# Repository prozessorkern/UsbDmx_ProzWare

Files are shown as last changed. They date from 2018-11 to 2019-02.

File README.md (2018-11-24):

# UsbDmx_ProzWare

Here you find the refactored hardware development (schematics and layout) of USB DMX from http://www.digital-enlightenment.de/usbdmx.htm.

Credit goes to Michael Dreschmann from http://www.digital-enlightenment.de.

This repo adds KiCad schematics and layout in SMD technology with a complete board design with onboard XLR connectors.

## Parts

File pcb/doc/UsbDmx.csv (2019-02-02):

Id | Designator | Package | Quantity | Designation | Supplier and ref
1 | U201,U206 | SO-8_3.9x4.9mm_P1.27mm | 2 | SN75176
2 | CON202 | NC3MAH_XLR_M | 1 | XLR3_M_GROUND
3 | CON101 | TC2050-IDC | 1 | 10PIN_ISP_AVR
4 | D101 | LED_SMD_0603 | 1 | LED
5 | CON201 | NC3FAH2_XLR_F | 1 | XLR3_F_GROUND
6 | D201 | LED_SMD_0603 | 1 | LED_TX
7 | D204 | LED_SMD_0603 | 1 | LED_DMX
8 | D205 | LED_SMD_0603 | 1 | LED_RX
9 | J102 | BARREL_JACK_CLIFF | 1 | Barrel_Jack
10 | U202,U204 | GULLWING_8 | 2 | 6N137
11 | U205 | SIP7 | 1 | AM2D-0505SZ
12 | L101,L201,L202,L204 | 1271.1001 | 4 | 1271.1001
13 | G*** | Shimatta_SolderMask | 1 | LOGO
14 | L203 | inductor_1812 | 1 | 18u
15 | U104 | SOIC-28W_8.7x18.7mm_Pitch1.27mm | 1 | AS6C6264
16 | U106 | TQFP-44_10x10mm_P0.8mm | 1 | ATMEGA8515-16AU
17 | C101,C106,C107,C108,C112,C114,C115,C117,C118,C119,C201,C202,C204,C205,C206,C210,C213,C215,C216 | C_0603_1608Metric_Pad1.05x0.95mm_HandSolder | 19 | 100n
18 | C102,C103 | C_0603_1608Metric_Pad1.05x0.95mm_HandSolder | 2 | 15p
19 | C104,C105,C111 | C_0805_2012Metric_Pad1.15x1.40mm_HandSolder | 3 | 100n
20 | C109 | CP_Radial_D4.0mm_P1.50mm | 1 | 1u
21 | C110 | CP_Radial_D10.0mm_P5.00mm | 1 | 470u
22 | C113 | CP_Radial_D6.3mm_P2.50mm | 1 | 100u
23 | C116 | CP_Radial_D5.0mm_P2.00mm | 1 | 10u
24 | C203,C212,C214 | C_Disc_D7.5mm_W5.0mm_P7.50mm | 3 | 470p 2kV
25 | C207,C211 | CP_Radial_D5.0mm_P2.00mm | 2 | 47u
26 | C208,C209 | C_0805_2012Metric_Pad1.15x1.40mm_HandSolder | 2 | 2u2
27 | D102,D103,D104,D105 | D_SMA_Handsoldering | 4 | SS15
28 | D202,D203,D206,D207 | D_MiniMELF | 4 | 1N4148
29 | F101 | Fuse_1206_3216Metric_Pad1.42x1.75mm_HandSolder | 1 | 0.375A
30 | J101 | USB_B_OST_USB-B1HSxx_Horizontal | 1 | USB_B
31 | JP101 | PinHeader_1x02_P2.54mm_Vertical | 1 | programming mode
32 | Q201,Q203 | SOT-23 | 2 | BC817
33 | Q202 | SOT-23 | 1 | BC807
34 | R101 | R_0603_1608Metric_Pad1.05x0.95mm_HandSolder | 1 | 100
35 | R102 | R_0603_1608Metric_Pad1.05x0.95mm_HandSolder | 1 | 1M
36 | R103,R104 | R_0603_1608Metric_Pad1.05x0.95mm_HandSolder | 2 | 22
37 | R105 | R_0603_1608Metric_Pad1.05x0.95mm_HandSolder | 1 | 1k5
38 | R106,R210,R219 | R_0603_1608Metric_Pad1.05x0.95mm_HandSolder | 3 | 1k
39 | R107,R108,R204,R208 | R_0603_1608Metric_Pad1.05x0.95mm_HandSolder | 4 | 10k
40 | R109,R110 | R_0603_1608Metric_Pad1.05x0.95mm_HandSolder | 2 | 2k2
41 | R111,R112,R211,R220 | R_0603_1608Metric_Pad1.05x0.95mm_HandSolder | 4 | 47k
42 | R201,R214 | R_MiniMELF_MMA-0204 | 2 | 120
43 | R202,R209,R212 | R_0603_1608Metric_Pad1.05x0.95mm_HandSolder | 3 | 470
44 | R203,R205 | R_MiniMELF_MMA-0204 | 2 | 1
45 | R206,R215,R216,R217 | R_MiniMELF_MMA-0204 | 4 | 10
46 | R207,R213,R218 | R_0603_1608Metric_Pad1.05x0.95mm_HandSolder | 3 | 220
47 | U101 | SOIC-20W_7.5x12.8mm_P1.27mm | 1 | 74LS573
48 | U102 | SOT-23-6 | 1 | USBLC6-2SC6
49 | U103 | SOIC-28W_7.5x17.9mm_P1.27mm | 1 | USBN9604-28M
50 | U105 | TO-263-2 | 1 | L7805
51 | U203,U207 | SOT-23_Handsoldering | 2 | PESD5V0S2BT
52 | Y101 | Crystal_HC49-U_Vertical | 1 | 24MHz
53 | REF** | KiCad-Logo2_8mm_SilkScreen | 1 | KiCad-Logo2_8mm_SilkScreen
54 | REF** | WEEE-Logo_8.4x12mm_SilkScreen | 1 | WEEE-Logo_8.4x12mm_SilkScreen
55 | REF** | ESD-Logo_8.9x8mm_SilkScreen | 1 | ESD-Logo_8.9x8mm_SilkScreen

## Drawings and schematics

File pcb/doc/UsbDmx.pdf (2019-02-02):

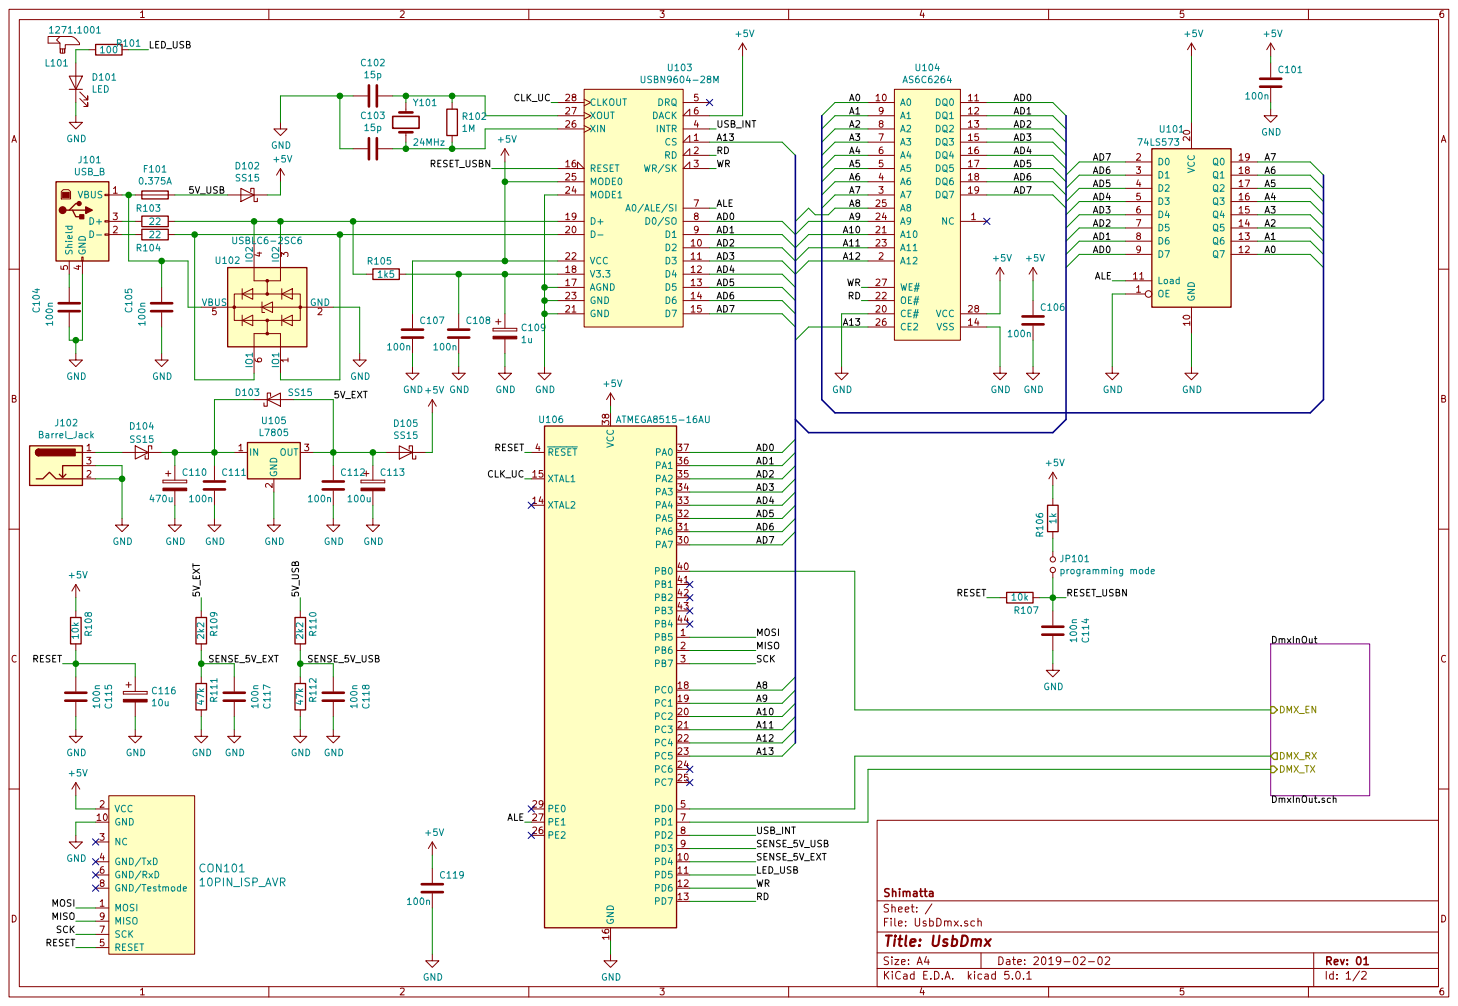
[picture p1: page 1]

RESET SCK MISO MOSI GND

File: UsbDmx.sch Sheet: / Shimatta

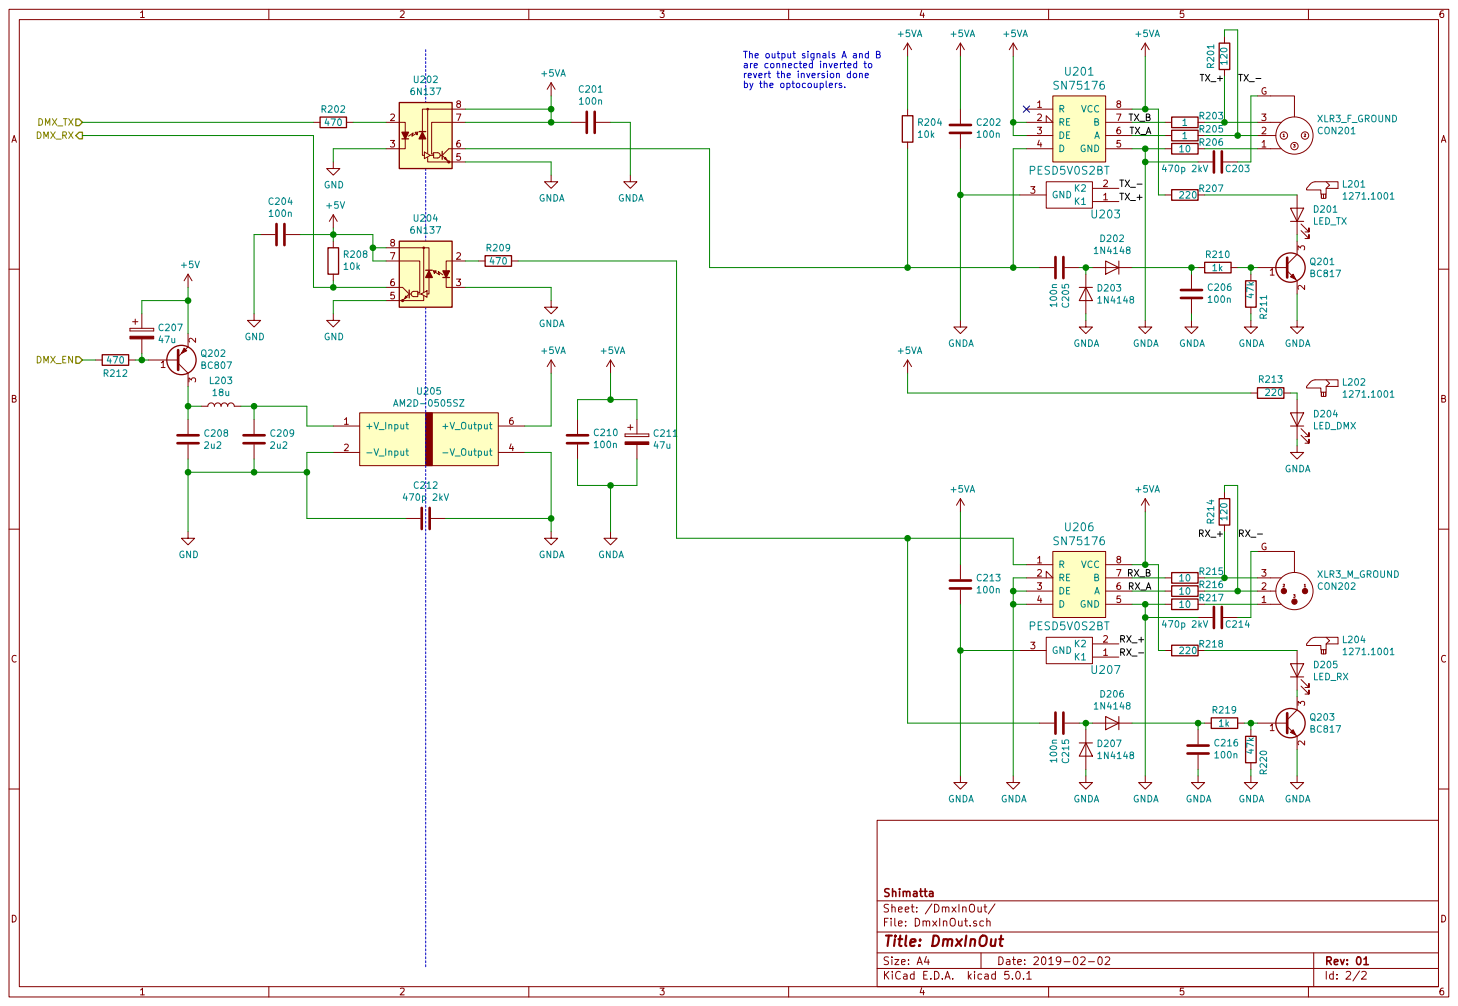
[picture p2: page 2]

The output signals A and B
are connected inverted to
revert the inversion done

Id: 2/2 Title: DmxInOut File: DmxInOut.sch Sheet: /DmxInOut/ Shimatta

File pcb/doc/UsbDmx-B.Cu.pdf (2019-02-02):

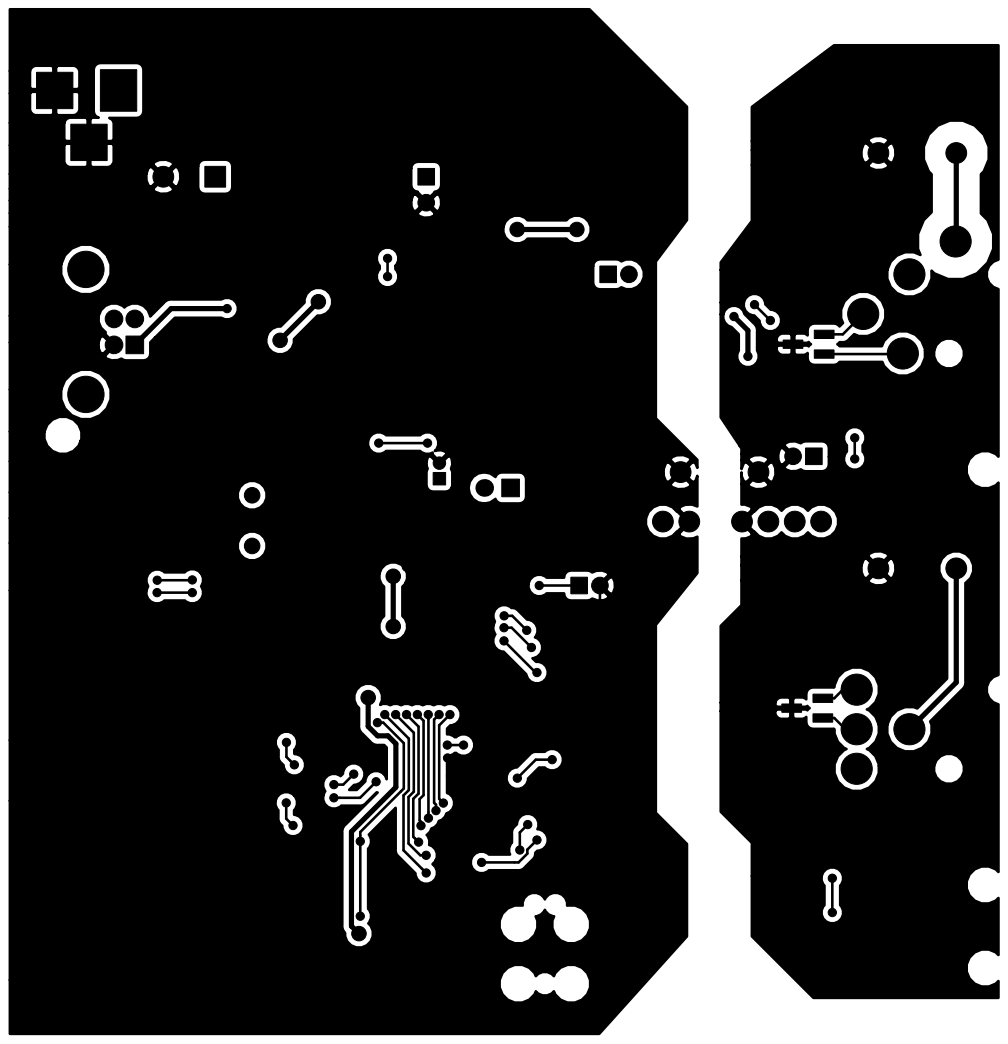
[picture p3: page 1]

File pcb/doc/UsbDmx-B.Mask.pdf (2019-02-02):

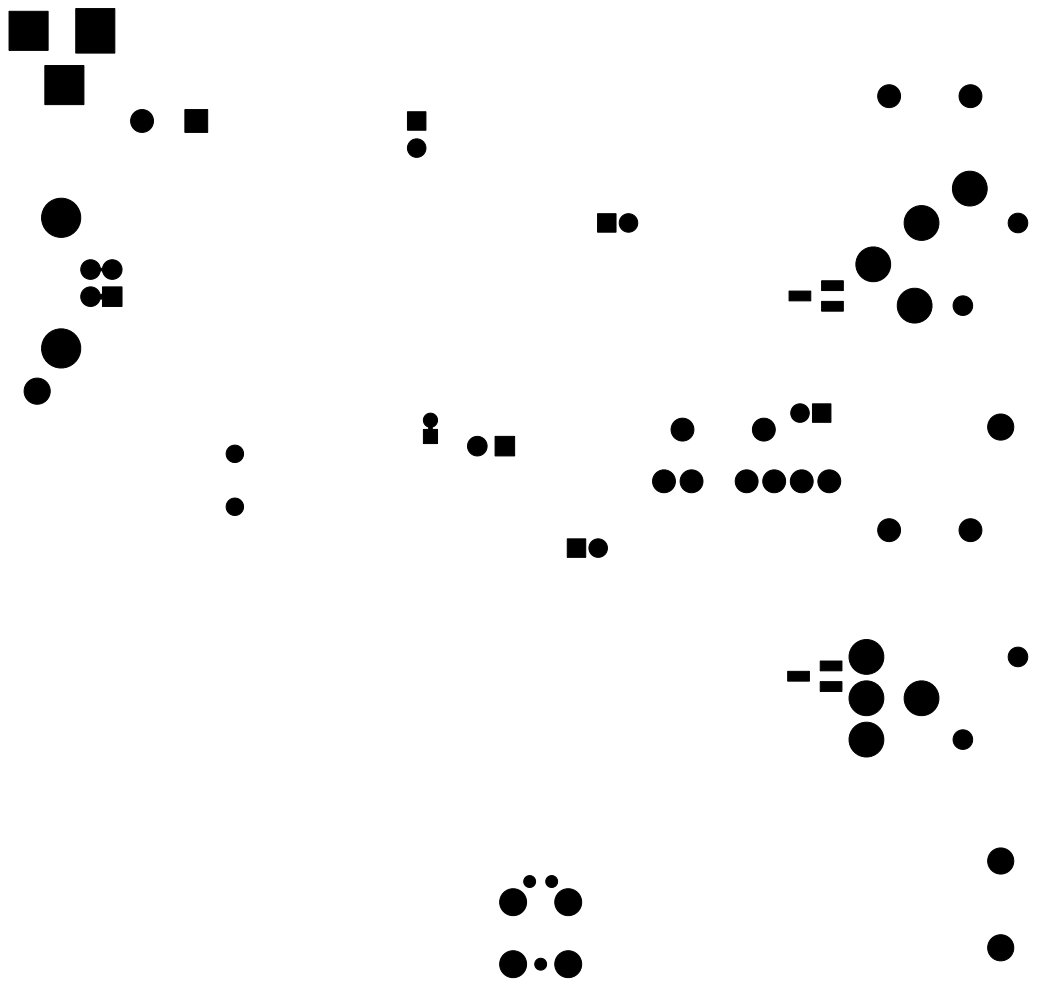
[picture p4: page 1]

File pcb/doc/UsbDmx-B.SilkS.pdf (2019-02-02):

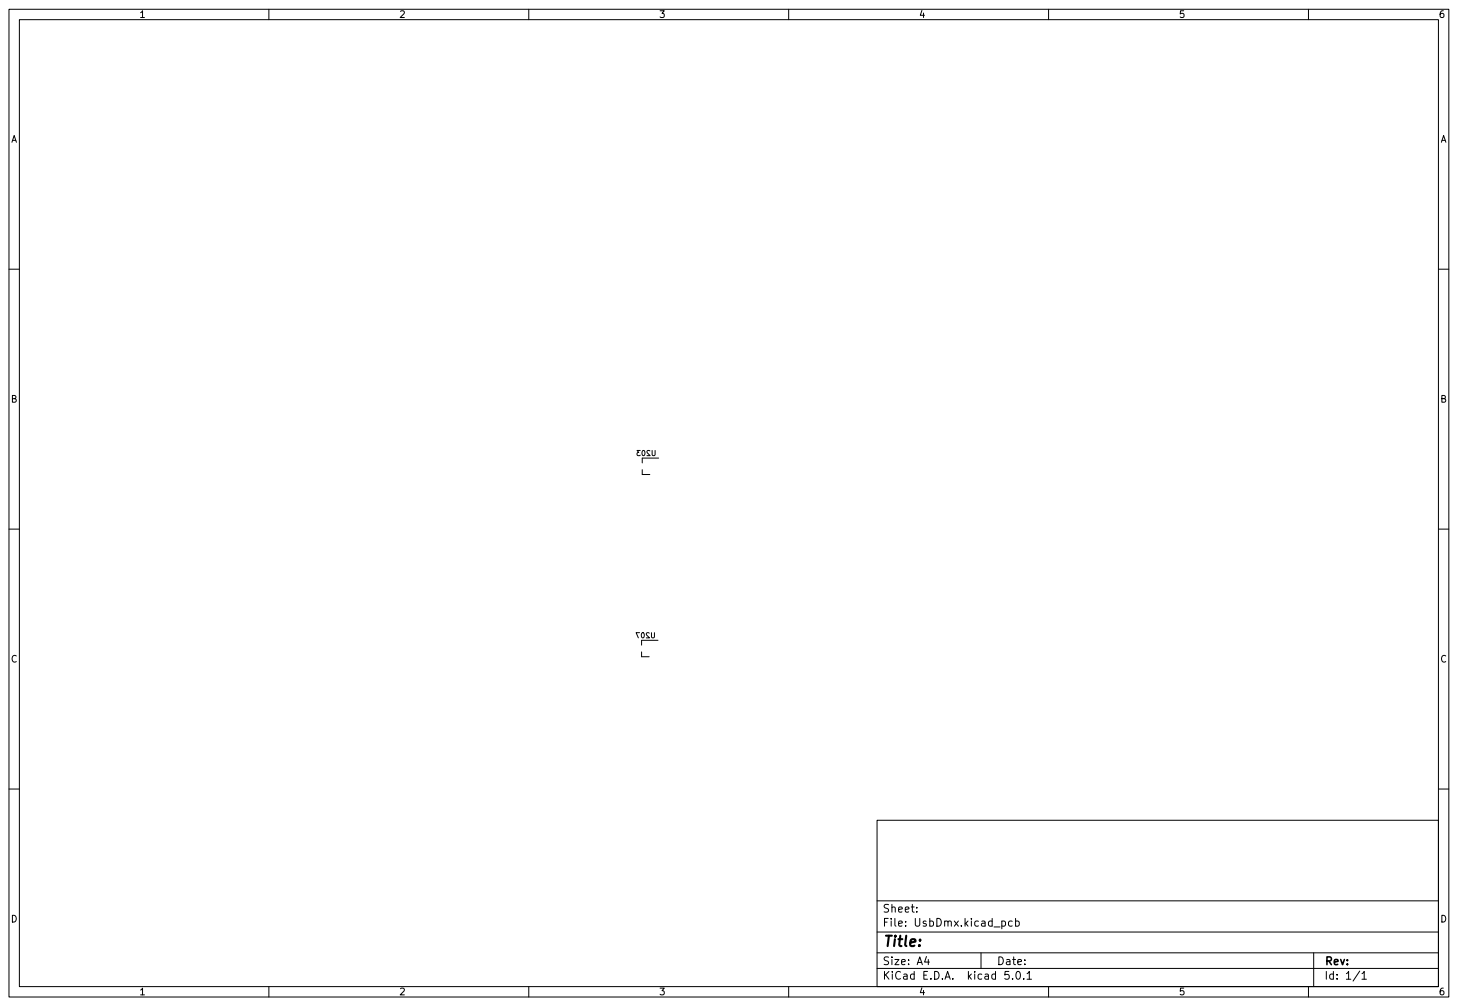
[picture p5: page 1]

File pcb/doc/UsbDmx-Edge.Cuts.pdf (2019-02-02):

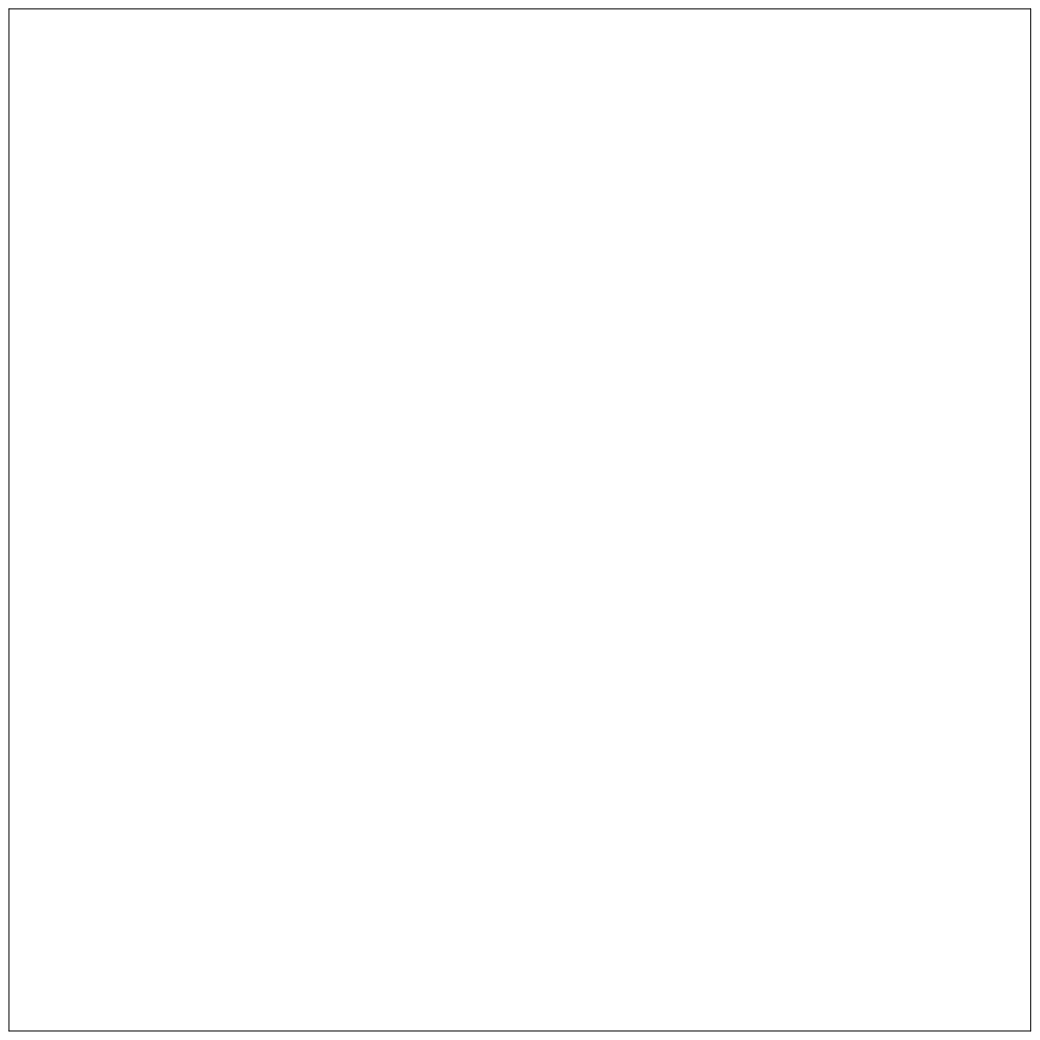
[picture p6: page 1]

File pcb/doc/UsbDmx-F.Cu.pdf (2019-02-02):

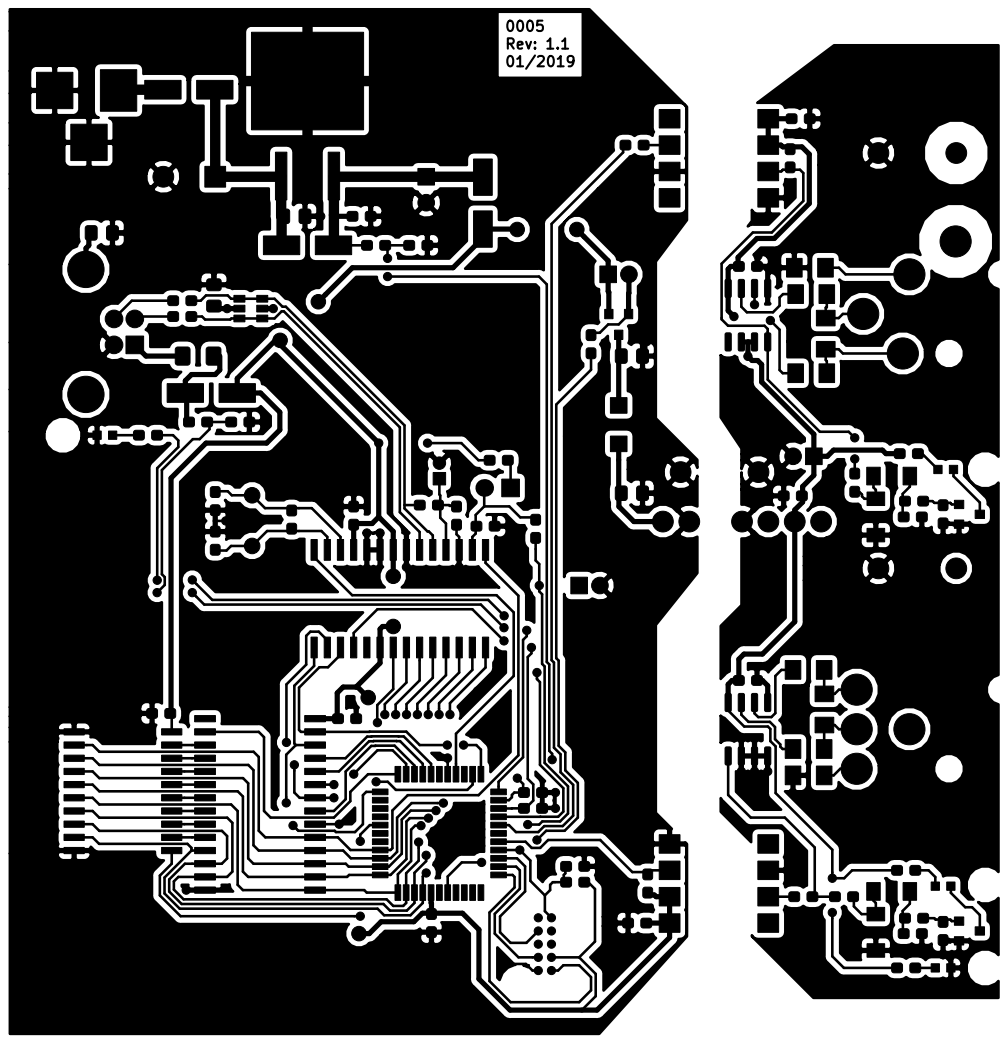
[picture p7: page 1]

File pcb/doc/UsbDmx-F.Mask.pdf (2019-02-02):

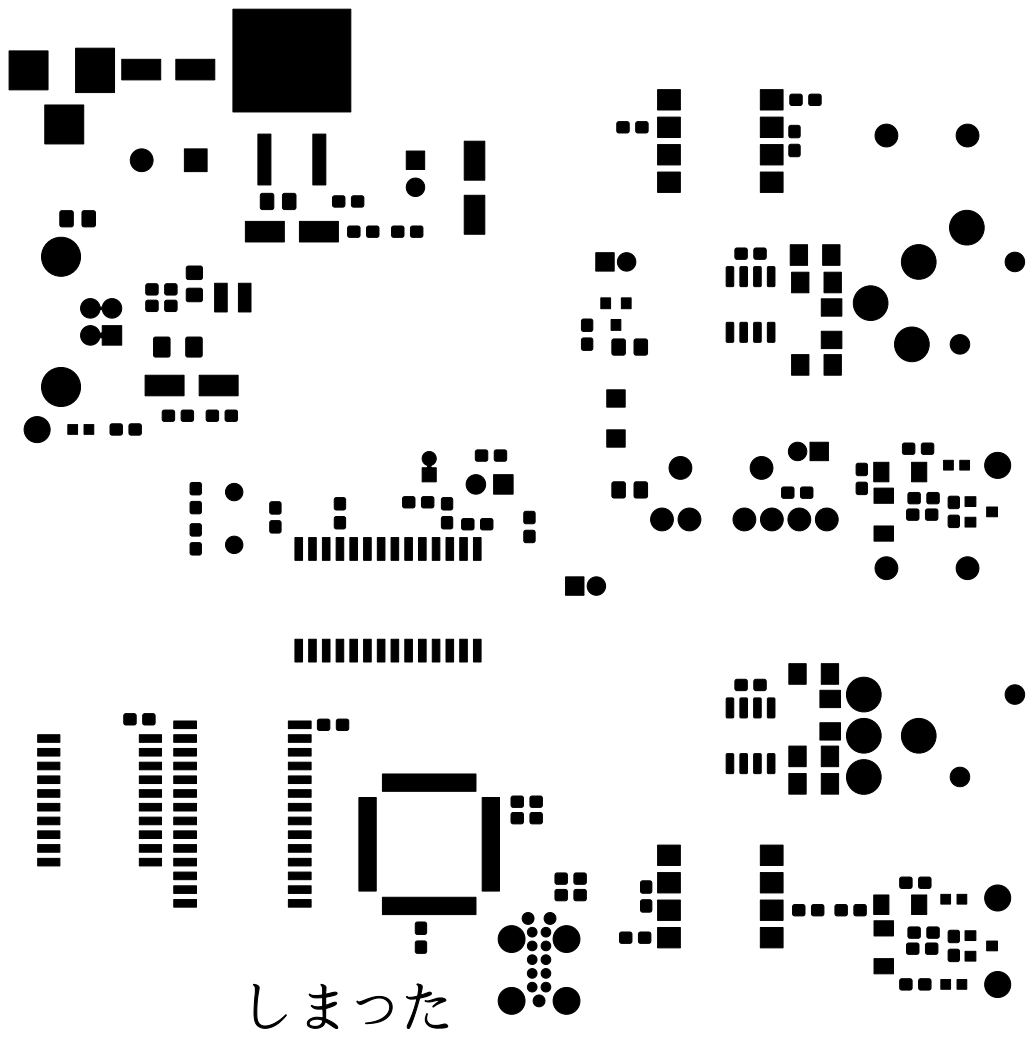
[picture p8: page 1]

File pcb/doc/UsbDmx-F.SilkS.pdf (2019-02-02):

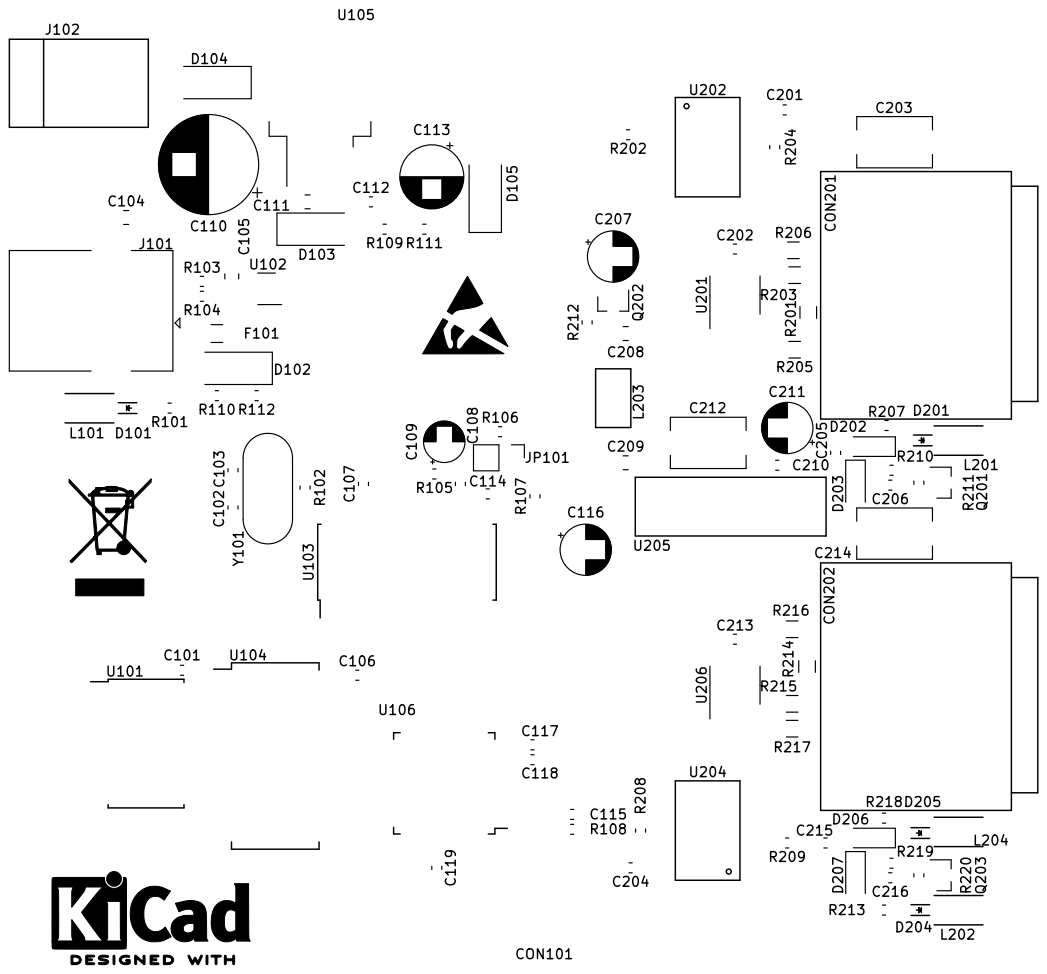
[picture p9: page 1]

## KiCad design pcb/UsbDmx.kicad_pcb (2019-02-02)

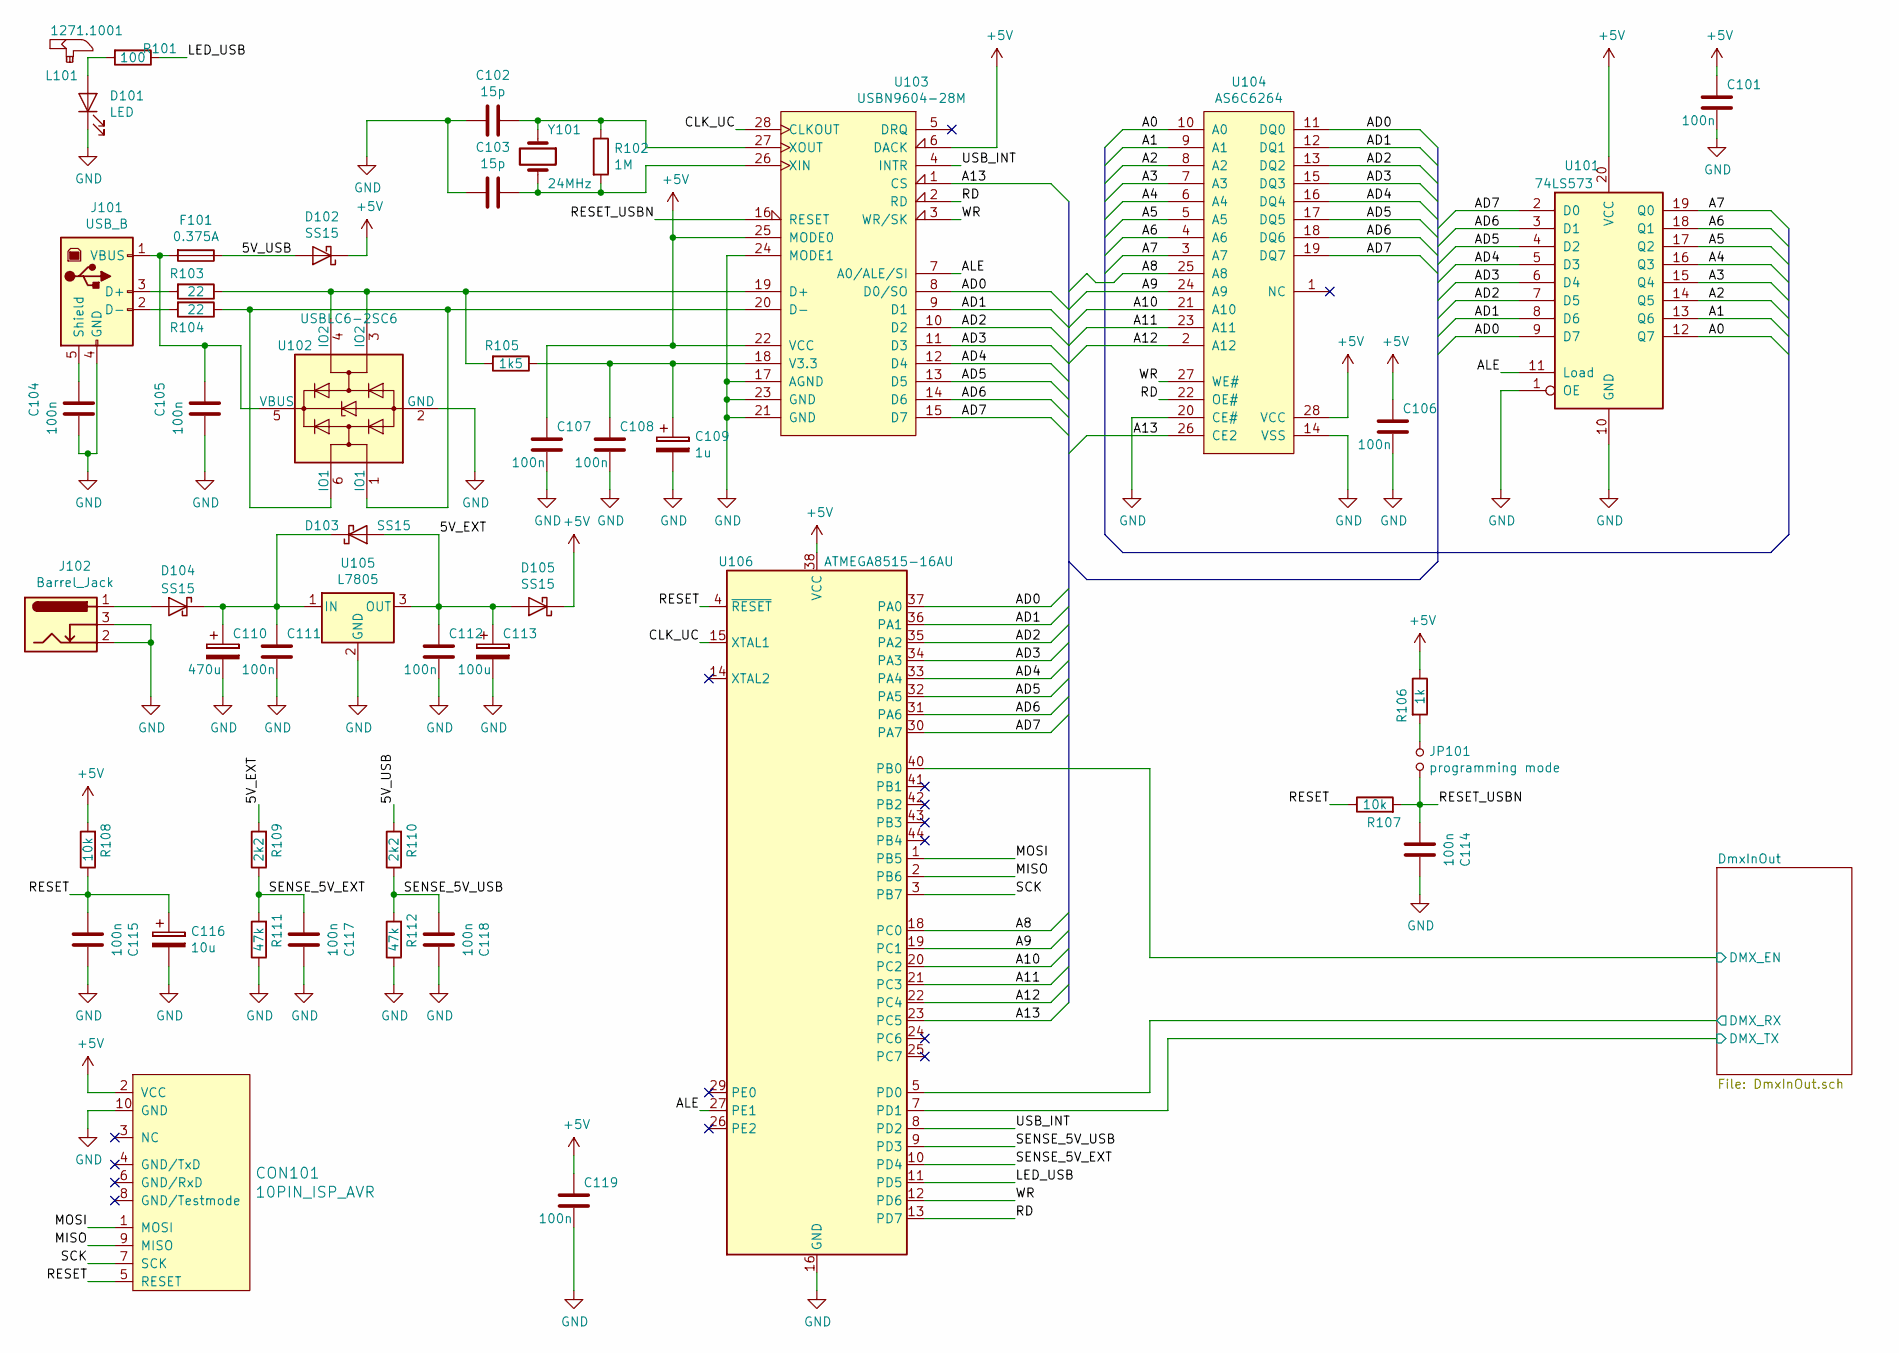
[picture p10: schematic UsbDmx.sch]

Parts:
C101, C106, C107, C108, C112, C114, C115, C117, C118, C119: 100n; C_0603_1608Metric_Pad1.05x0.95mm_HandSolder
C102, C103: 15p; C_0603_1608Metric_Pad1.05x0.95mm_HandSolder
C104, C105, C111: 100n; C_0805_2012Metric_Pad1.15x1.40mm_HandSolder
C109: 1u; CP_Radial_D4.0mm_P1.50mm
C110: 470u; CP_Radial_D10.0mm_P5.00mm
C113: 100u; CP_Radial_D6.3mm_P2.50mm
C116: 10u; CP_Radial_D5.0mm_P2.00mm
CON101: 10PIN_ISP_AVR; TC2050-IDC
D101: LED; LED_SMD_0603
D102, D103, D104, D105: SS15; D_SMA_Handsoldering
F101: 0.375A; Fuse_1206_3216Metric_Pad1.42x1.75mm_HandSolder
J101: USB_B; USB_B_OST_USB-B1HSxx_Horizontal
J102: Barrel_Jack; BARREL_JACK_CLIFF
JP101: programming mode; PinHeader_1x02_P2.54mm_Vertical
L101: 1271.1001
R101: 100; R_0603_1608Metric_Pad1.05x0.95mm_HandSolder
R102: 1M; R_0603_1608Metric_Pad1.05x0.95mm_HandSolder
R103, R104: 22; R_0603_1608Metric_Pad1.05x0.95mm_HandSolder
R105: 1k5; R_0603_1608Metric_Pad1.05x0.95mm_HandSolder
R106: 1k; R_0603_1608Metric_Pad1.05x0.95mm_HandSolder
R107, R108: 10k; R_0603_1608Metric_Pad1.05x0.95mm_HandSolder
R109, R110: 2k2; R_0603_1608Metric_Pad1.05x0.95mm_HandSolder
R111, R112: 47k; R_0603_1608Metric_Pad1.05x0.95mm_HandSolder
U101: 74LS573; SOIC-20W_7.5x12.8mm_P1.27mm
U102: USBLC6-2SC6; SOT-23-6
U103: USBN9604-28M; SOIC-28W_7.5x17.9mm_P1.27mm
U104: AS6C6264; SOIC-28W_8.7x18.7mm_Pitch1.27mm
U105: L7805; TO-263-2
U106: ATMEGA8515-16AU; TQFP-44_10x10mm_P0.8mm
Y101: 24MHz; Crystal_HC49-U_Vertical

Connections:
+5V: C101.1, C106.1, C107.1, C119.1, CON101.2 (VCC), D102.1 (K), D105.1 (K), R106.1, R108.2, U101.20 (VCC), U103.6 (DACK), U103.22 (VCC), U103.25 (MODE0), U104.28 (VCC), U106.38 (VCC); also elsewhere on the board
/5V_EXT: C112.1, C113.1, D103.2 (A), D105.2 (A), R109.2, U105.3 (OUT)
/5V_USB: D102.2 (A), F101.1, R110.2
/A0: U101.12 (Q7), U104.10 (A0)
/A1: U101.13 (Q6), U104.9 (A1)
/A2: U101.14 (Q5), U104.8 (A2)
/A3: U101.15 (Q4), U104.7 (A3)
/A4: U101.16 (Q3), U104.6 (A4)
/A5: U101.17 (Q2), U104.5 (A5)
/A6: U101.18 (Q1), U104.4 (A6)
/A7: U101.19 (Q0), U104.3 (A7)
/A8: U104.25 (A8), U106.18 (PC0)
/A9: U104.24 (A9), U106.19 (PC1)
/A10: U104.21 (A10), U106.20 (PC2)
/A11: U104.23 (A11), U106.21 (PC3)
/A12: U104.2 (A12), U106.22 (PC4)
/A13: U103.1 (CS), U104.26 (CE2), U106.23 (PC5)
/AD0: U101.9 (D7), U103.8 (D0/SO), U104.11 (DQ0), U106.37 (PA0)
/AD1: U101.8 (D6), U103.9 (D1), U104.12 (DQ1), U106.36 (PA1)
/AD2: U101.7 (D5), U103.10 (D2), U104.13 (DQ2), U106.35 (PA2)
/AD3: U101.6 (D4), U103.11 (D3), U104.15 (DQ3), U106.34 (PA3)
/AD4: U101.5 (D3), U103.12 (D4), U104.16 (DQ4), U106.33 (PA4)
/AD5: U101.4 (D2), U103.13 (D5), U104.17 (DQ5), U106.32 (PA5)
/AD6: U101.3 (D1), U103.14 (D6), U104.18 (DQ6), U106.31 (PA6)
/AD7: U101.2 (D0), U103.15 (D7), U104.19 (DQ7), U106.30 (PA7)
/ALE: U101.11 (Load), U103.7 (A0/ALE/SI), U106.27 (PE1)
/CLK_UC: U103.28 (CLKOUT), U106.15 (XTAL1)
/DmxInOut/DMX_EN: U106.40 (PB0); also elsewhere on the board
/DmxInOut/DMX_RX: U106.5 (PD0); also elsewhere on the board
/DmxInOut/DMX_TX: U106.7 (PD1); also elsewhere on the board
/LED_USB: R101.1, U106.11 (PD5)
/MISO: CON101.9 (MISO), U106.2 (PB6)
/MOSI: CON101.1 (MOSI), U106.1 (PB5)
/RD: U103.2 (RD), U104.22 (OE#), U106.13 (PD7)
/RESET: C115.2, C116.1, CON101.5 (RESET), R107.1, R108.1, U106.4 (~RESET)
/RESET_USBN: C114.2, JP101.2, R107.2, U103.16 (RESET)
/SCK: CON101.7 (SCK), U106.3 (PB7)
/SENSE_5V_EXT: C117.2, R109.1, R111.2, U106.10 (PD4)
/SENSE_5V_USB: C118.2, R110.1, R112.2, U106.9 (PD3)
/USB_INT: U103.4 (INTR), U106.8 (PD2)
/WR: U103.3 (WR/SK), U104.27 (WE#), U106.12 (PD6)
GND: C101.2, C102.2, C103.2, C104.2, C105.2, C106.2, C107.2, C108.2, C109.2, C110.2, C111.2, C112.2, C113.2, C114.1, C115.1, C116.2, C117.1, C118.1, C119.2, CON101.10 (GND), D101.1 (K), J101.4 (GND), J102.2, J102.3, R111.1, R112.1, U101.1 (OE), U101.10 (GND), U102.2 (GND), U103.17 (AGND), U103.21 (GND), U103.23 (GND), U103.24 (MODE1), U104.14 (VSS), U104.20 (CE#), U105.2 (GND), U106.16 (GND); also elsewhere on the board
unnamed: C102.1, R102.1, U103.27 (XOUT), Y101.1
unnamed: C103.1, R102.2, U103.26 (XIN), Y101.2
unnamed: C104.1, J101.5 (Shield)
unnamed: C105.1, F101.2, J101.1 (VBUS), U102.5 (VBUS)
unnamed: C108.1, C109.1, R105.1, U103.18 (V3.3)
unnamed: C110.1, C111.1, D103.1 (K), D104.1 (K), U105.1 (IN)
unnamed: D101.2 (A), R101.2
unnamed: D104.2 (A), J102.1
unnamed: J101.2 (D-), R104.2
unnamed: J101.3 (D+), R103.2
unnamed: JP101.1, R106.2
unnamed: R103.1, R105.2, U102.3 (IO2), U102.4 (IO2), U103.19 (D+)
unnamed: R104.1, U102.1 (IO1), U102.6 (IO1), U103.20 (D-)

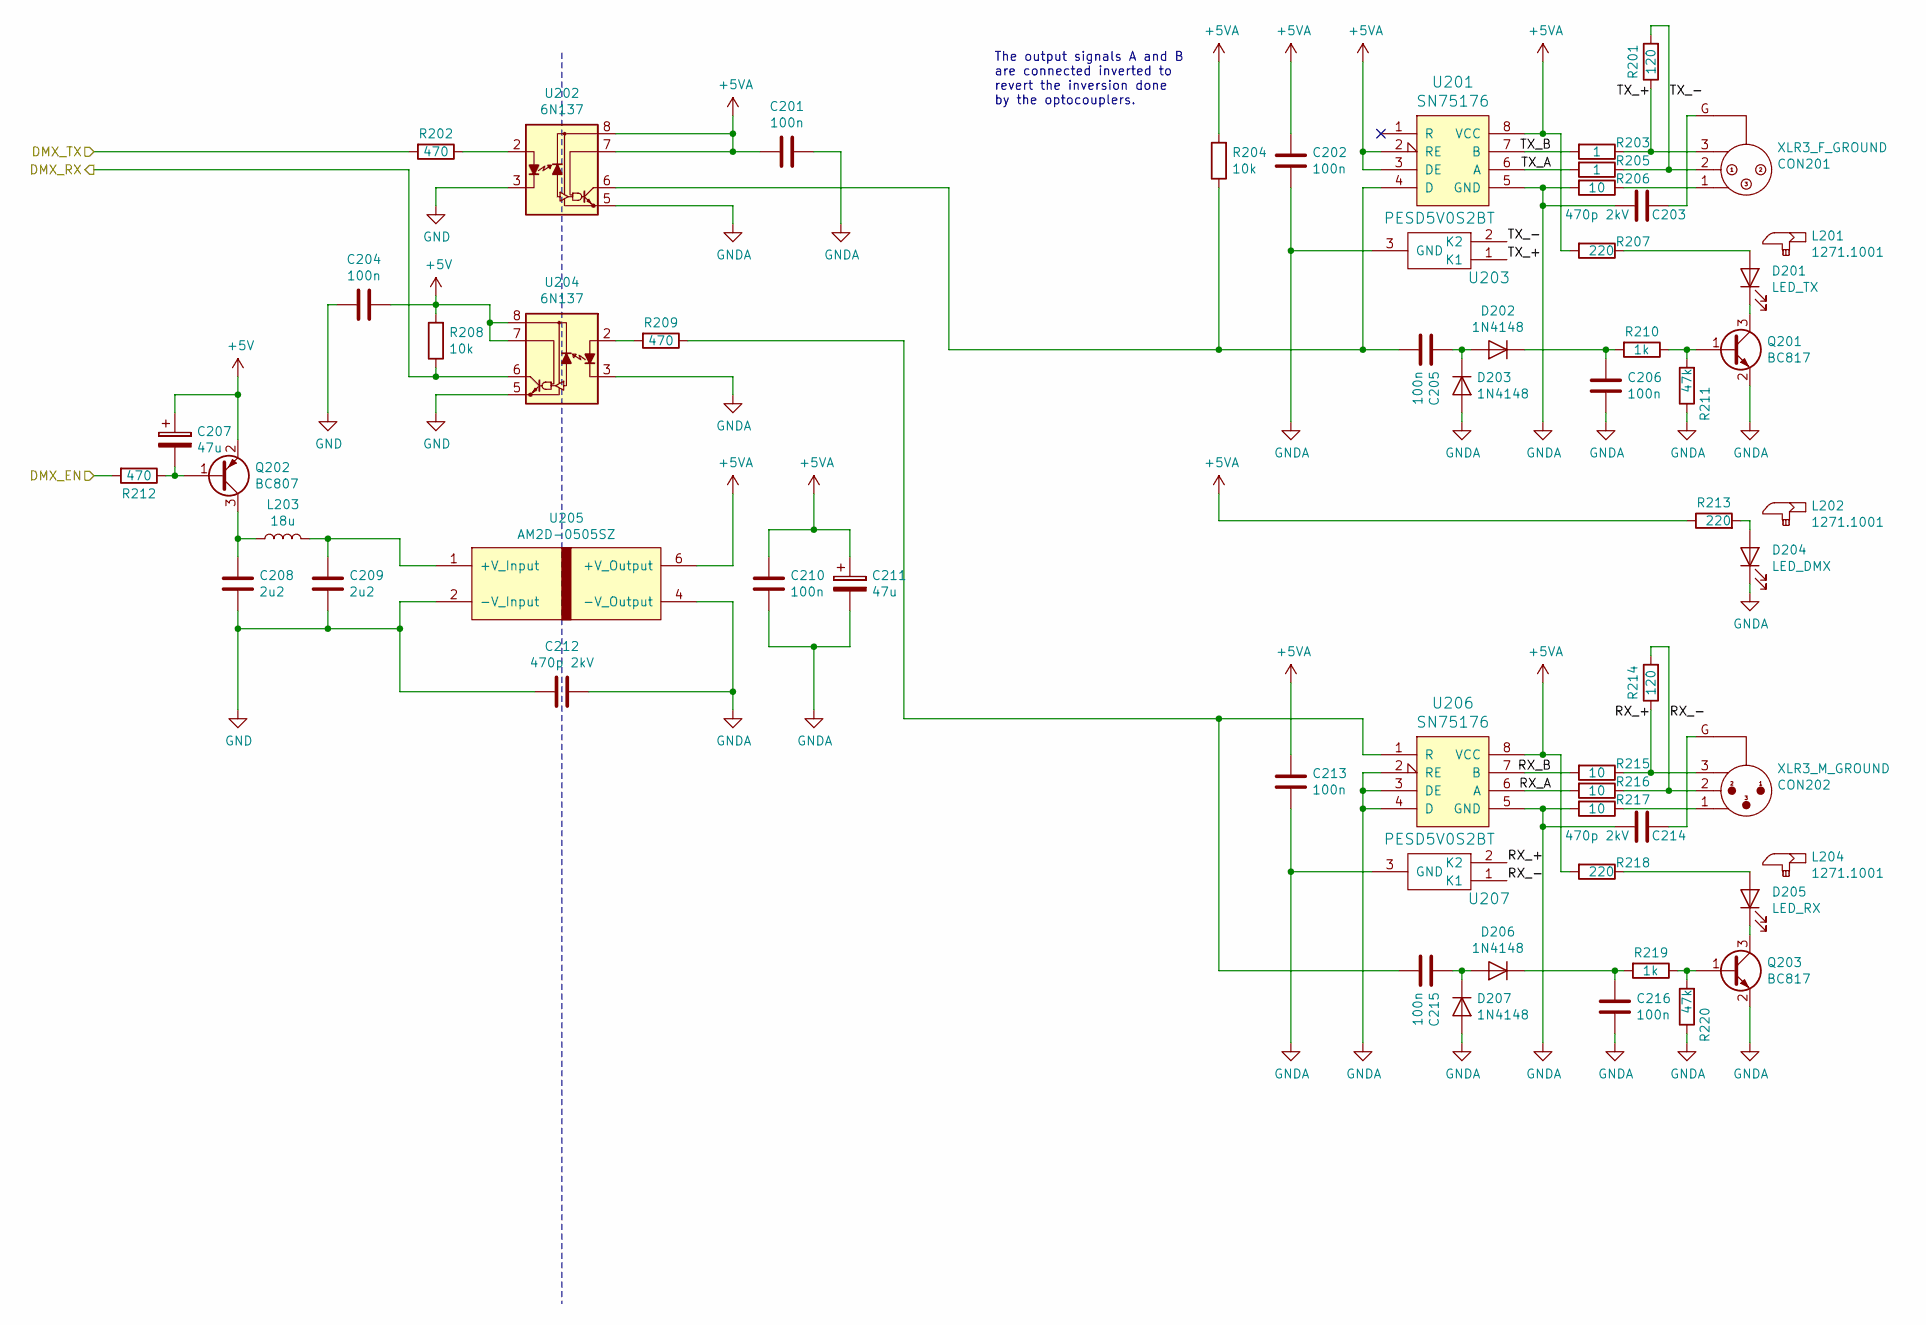
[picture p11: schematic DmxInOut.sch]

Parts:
C201, C202, C204, C205, C206, C210, C213, C215, C216: 100n; C_0603_1608Metric_Pad1.05x0.95mm_HandSolder
C203, C212, C214: 470p 2kV; C_Disc_D7.5mm_W5.0mm_P7.50mm
C207, C211: 47u; CP_Radial_D5.0mm_P2.00mm
C208, C209: 2u2; C_0805_2012Metric_Pad1.15x1.40mm_HandSolder
CON201: XLR3_F_GROUND; NC3FAH2_XLR_F
CON202: XLR3_M_GROUND; NC3MAH_XLR_M
D201: LED_TX; LED_SMD_0603
D202, D203, D206, D207: 1N4148; D_MiniMELF
D204: LED_DMX; LED_SMD_0603
D205: LED_RX; LED_SMD_0603
L201, L202, L204: 1271.1001
L203: 18u; inductor_1812
Q201, Q203: BC817; SOT-23
Q202: BC807; SOT-23
R201, R214: 120; R_MiniMELF_MMA-0204
R202, R209, R212: 470; R_0603_1608Metric_Pad1.05x0.95mm_HandSolder
R203, R205: 1; R_MiniMELF_MMA-0204
R204, R208: 10k; R_0603_1608Metric_Pad1.05x0.95mm_HandSolder
R206, R215, R216, R217: 10; R_MiniMELF_MMA-0204
R207, R213, R218: 220; R_0603_1608Metric_Pad1.05x0.95mm_HandSolder
R210, R219: 1k; R_0603_1608Metric_Pad1.05x0.95mm_HandSolder
R211, R220: 47k; R_0603_1608Metric_Pad1.05x0.95mm_HandSolder
U201, U206: SN75176; SO-8_3.9x4.9mm_P1.27mm
U202, U204: 6N137; GULLWING_8
U203, U207: PESD5V0S2BT; SOT-23_Handsoldering
U205: AM2D-0505SZ; SIP7

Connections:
+5V: C204.1, C207.1, Q202.2 (E), R208.2, U204.7, U204.8; also elsewhere on the board
+5VA: C201.2, C202.2, C210.2, C211.1, C213.2, R204.2, R207.2, R213.1, R218.2, U201.2 (RE), U201.3 (DE), U201.8 (VCC), U202.7, U202.8, U205.6 (+V_Output), U206.8 (VCC)
/DmxInOut/DMX_EN: R212.2; also elsewhere on the board
/DmxInOut/DMX_RX: R208.1, U204.6; also elsewhere on the board
/DmxInOut/DMX_TX: R202.2; also elsewhere on the board
/DmxInOut/RX_+: CON202.3, R214.1, R215.1, U207.2 (K2)
/DmxInOut/RX_-: CON202.2, R214.2, R216.1, U207.1 (K1)
/DmxInOut/RX_A: R216.2, U206.6 (A)
/DmxInOut/RX_B: R215.2, U206.7 (B)
/DmxInOut/TX_+: CON201.3, R201.1, R203.1, U203.1 (K1)
/DmxInOut/TX_-: CON201.2, R201.2, R205.1, U203.2 (K2)
/DmxInOut/TX_A: R205.2, U201.6 (A)
/DmxInOut/TX_B: R203.2, U201.7 (B)
GND: C204.2, C208.2, C209.2, C212.2, U202.3, U204.5, U205.2 (-V_Input); also elsewhere on the board
GNDA: C201.1, C202.1, C203.2, C206.1, C210.1, C211.2, C212.1, C213.1, C214.2, C216.1, D203.2 (A), D204.1 (K), D207.2 (A), Q201.2 (E), Q203.2 (E), R206.2, R211.1, R217.2, R220.1, U201.5 (GND), U202.5, U203.3 (GND), U204.3, U205.4 (-V_Output), U206.2 (RE), U206.3 (DE), U206.4 (D), U206.5 (GND), U207.3 (GND)
unnamed: C203.1, CON201.G
unnamed: C205.1, R204.1, U201.4 (D), U202.6
unnamed: C205.2, D202.2 (A), D203.1 (K)
unnamed: C206.2, D202.1 (K), R210.2
unnamed: C207.2, Q202.1 (B), R212.1
unnamed: C208.1, L203.1, Q202.3 (C)
unnamed: C209.1, L203.2, U205.1 (+V_Input)
unnamed: C214.1, CON202.G
unnamed: C215.1, R209.1, U206.1 (R)
unnamed: C215.2, D206.2 (A), D207.1 (K)
unnamed: C216.2, D206.1 (K), R219.2
unnamed: CON201.1, R206.1
unnamed: CON202.1, R217.1
unnamed: D201.1 (K), Q201.3 (C)
unnamed: D201.2 (A), R207.1
unnamed: D204.2 (A), R213.2
unnamed: D205.1 (K), Q203.3 (C)
unnamed: D205.2 (A), R218.1
unnamed: Q201.1 (B), R210.1, R211.2
unnamed: Q203.1 (B), R219.1, R220.2
unnamed: R202.1, U202.2
unnamed: R209.2, U204.2

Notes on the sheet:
The output signals A and B are connected inverted to revert the inversion done by the optocouplers.

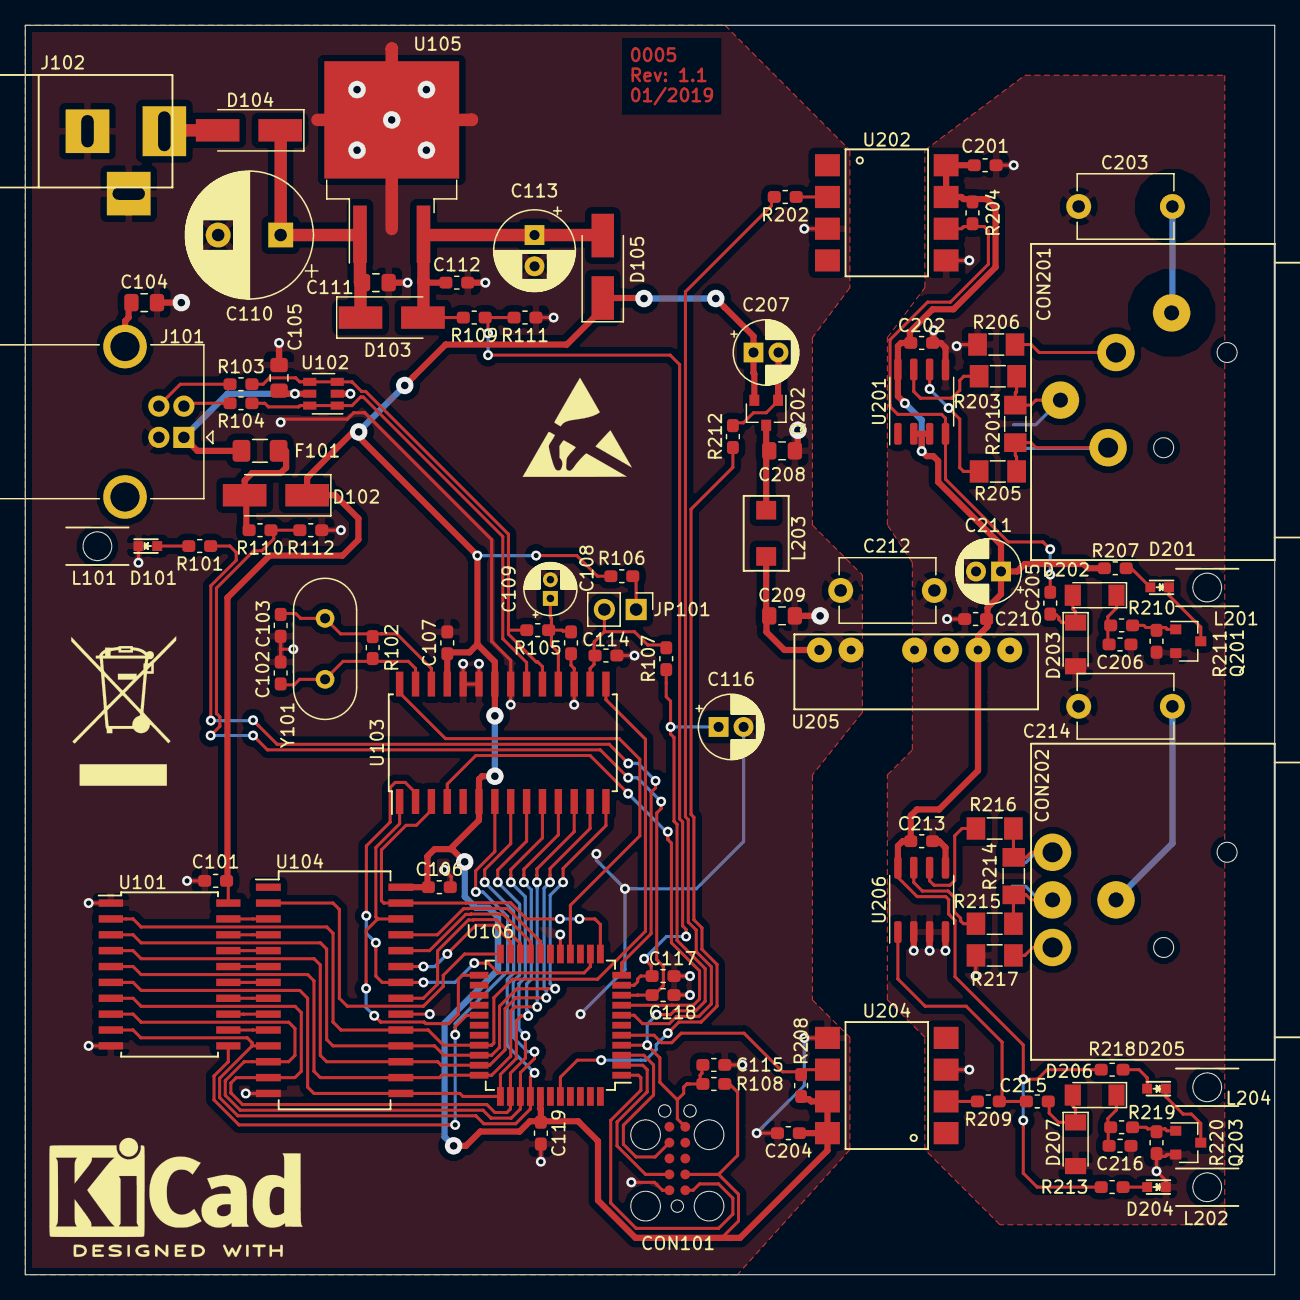
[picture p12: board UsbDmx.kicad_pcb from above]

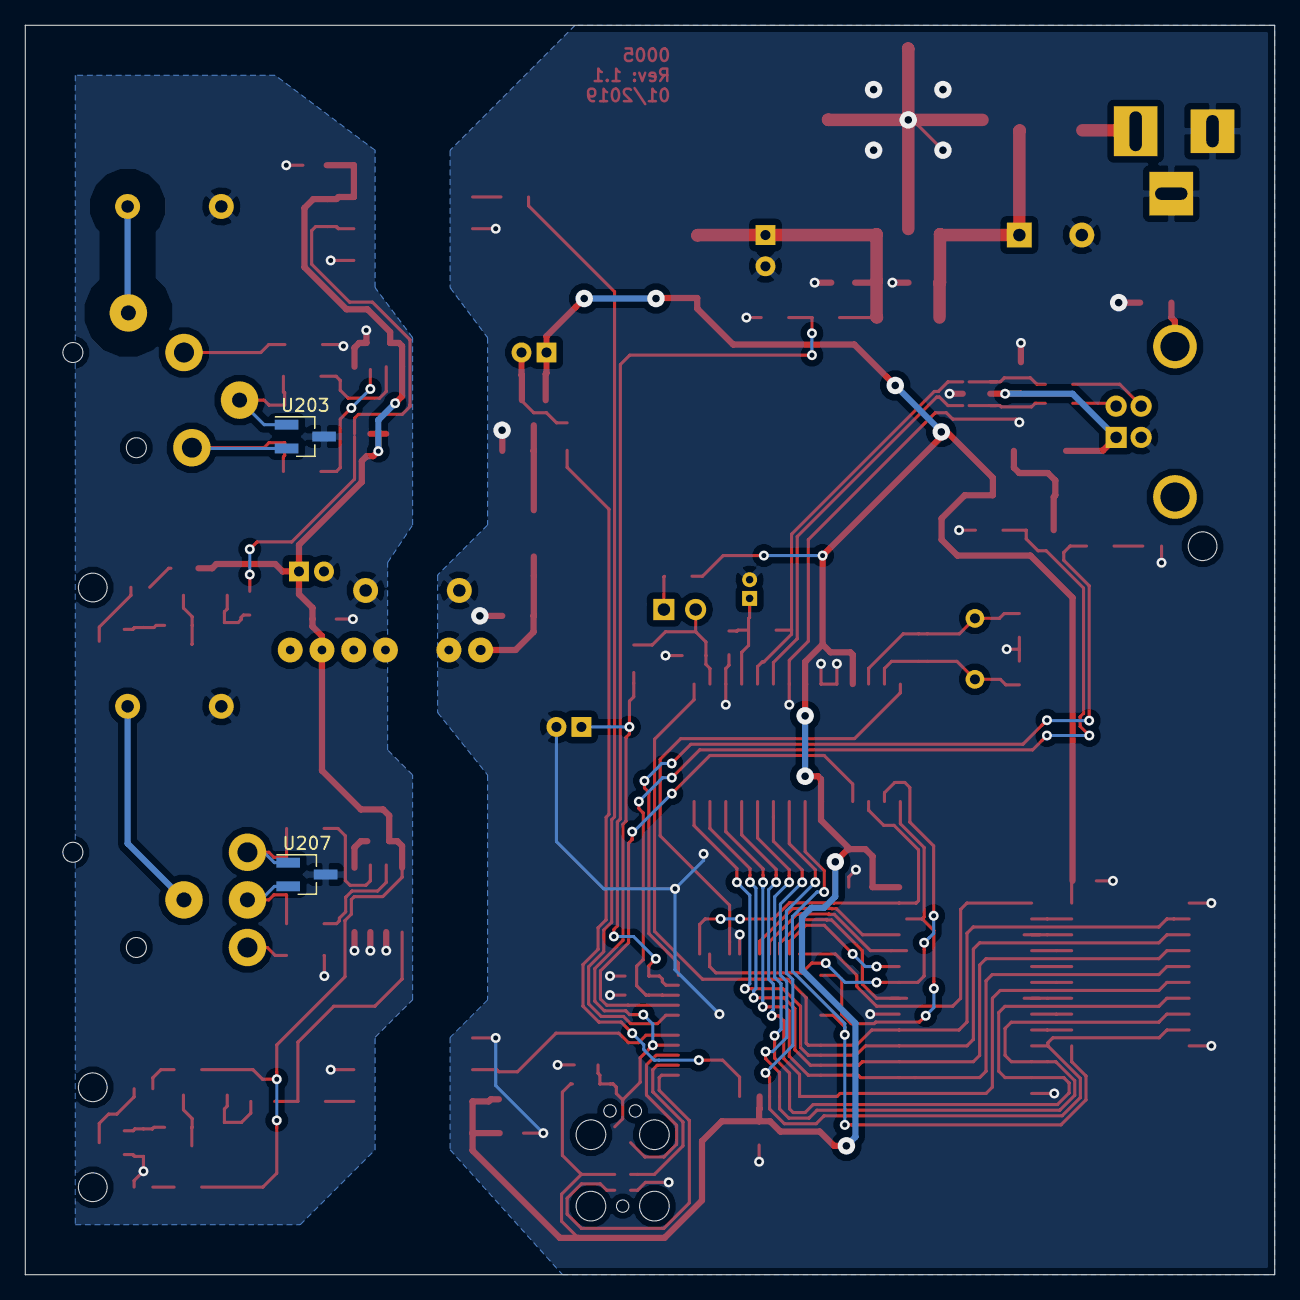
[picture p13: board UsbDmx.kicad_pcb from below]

Board: 2 copper layers, 100.0 x 100.0 mm, 108 parts (2 on the bottom side), 87 nets.

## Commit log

2018-11-24 Added the KiCad project with the nearly finished schematics
    [DmxInOut.sch, UsbDmx.kicad_pcb, UsbDmx.sch]
2018-11-25 Started footprint association
    [DmxInOut.sch, UsbDmx.sch]
2018-11-27 finished footprint association
    [DmxInOut.sch, UsbDmx.sch]
2018-12-18 startet layouting
    Startet to create a Layout
    [DmxInOut.sch, UsbDmx.kicad_pcb, UsbDmx.sch]
2018-12-20 Finished layout
    Added esd protection diodes to the dmx interface
    Routed everything
    added ground planes
    added some logos...
    [DmxInOut.sch, UsbDmx.kicad_pcb, UsbDmx.sch]
2018-12-24 final release 1.0
    [UsbDmx-B.Cu.gbl, UsbDmx-B.Mask.gbs, UsbDmx-B.SilkS.gbo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]
2019-01-20 Bugfixing after testing prototype
    Added a different pullup mechanism during programming to keep the USBN active during reset. Otherwise the ATmega loses its clock.
    Fixed the broken pin association of the DMX connectors.
    [DmxInOut.sch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]
2019-01-23 fixed XLR connectors, LEDs and Reset
    [DmxInOut.sch, UsbDmx.kicad_pcb, UsbDmx.sch]
2019-01-29 changed footprints to fit better the real parts
    [DmxInOut.sch, UsbDmx.kicad_pcb, UsbDmx.sch]
2019-01-29 fixed silkscreen
    [UsbDmx.kicad_pcb]
2019-02-02 Updated all KiCad symbols and footprints to the ones on the current master branch of their symbols created all documents to produce this thing
    [DmxInOut.sch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]
